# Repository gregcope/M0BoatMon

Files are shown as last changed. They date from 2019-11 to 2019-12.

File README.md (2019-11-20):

ABoatMon
========

A Moteino M0 (hence the M0) Boat Monitoring solution!

Intro
=====

A reimplementation, and extension of https://github.com/gregcope/piboatmon, as the original consumed too much power.  This is designed with the following goals;
* Be very, very low power
* Chargable from 12-24V 
* Has a rechargable LIPO battery

The present version is made from COTS parts to make life easy at the deign/proto stage.  However the code should be transferable.

Parts
=====
* [Adafruit Ultimate GPS](https://www.adafruit.com/product/746) - any 3.3v UART GPS would do, however needs an enable pin and vbat GPS almanac backup
* [Adafruit Fona](https://www.adafruit.com/product/1946) - any 3.3v UART GSM modem would do, although we do use the battery charging on the fona
* [Low power Moteino M0](https://lowpowerlab.com/shop/product/184) 
* [Mini Step Down Regulator Voltag Power Supply Module 4.5v~55v to 5v](https://www.ebay.co.uk/sch/i.html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).  Specifically the one with an enable pin and low power in off mode (<10ua).  Needs to supply 500ma+ (600ma is fine) and deal with 11-30v on the input to work on 12V or 24V systems.  Needs to supply 5V for the lipo charger.  Efficiency is not a massive issue as the regulator is off most of the time, only on to charge occassionally.
* [DS18B20 Waterproof Digital Probe Temperature Sensor with Silicone Cable (higher temp) Thermometer](https://www.ebay.co.uk/sch/i.html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)
* [12V 12mm LED Power Push Button Switch Momentary Waterproof Metal 4 Pin](https://www.ebay.co.uk/sch/i.html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)
* 1200mah LIPO Battery (any single cell LIPO with a JST would do)
* Bilge Switch (any normally closed, simple switch would do)

External Libs
=======

* [Tinygps++](https://github.com/mikalhart/TinyGPSPlus) - A class to deal with GPS
* [Lowpower](https://github.com/LowPowerLab/LowPower) - A class to help with Sleep modes
* Eeprom - Save Eeprom state
* [OneWire](https://github.com/PaulStoffregen/OneWire) - DS18B20 Temp sensor lib

Internal Classes
========
* Device - A base, or standlone class to control power to devices via a Digital pin
* Config - A class to provide a config object to store Eeprom state
* CRC8 - CRC checksum (for config saving)
* Sleep - Simple wrapper to LowPower sleep

High Level Logic
================

* Switches is on setup configures all the required parts
* Loop every 8 secs and checks;
* Bilge switch
* Every 4 mins checks the batteries
* and if above 13.7v (ie charging) enables the onboard lipo charger
* Reports bilge switch or low BatV
* Every Hour;
* Checkst the above
* Checks location
* If any of the above are out of band;
* Send a message

HowTo
=====

1. Open a command terminal, and change cd to where your Ardunio IDE stores code
```cd Documents/Arduino```
2. Clone the repo
```git clone https://github.com/gregcope/ABoatMon.git```
3. Open Ardunio IDE and open ```ABoatMon.ino```

http://arduino.stackexchange.com/questions/348/how-to-organize-my-arduino-projects-structure-for-easy-source-control

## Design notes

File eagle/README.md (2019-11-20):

# Eagle Files

0. Uses Sparkfun DRC file
1. ERC and DRC check clean
2. Top and bottom Copper Pour
3. Nets Classes use 24 mil width and 16mil clearance
4. Polygons use Isolate 12 mil
5. Layer 26 bNames - bottom silkscreen has board dimensions on it

## Design

0. I may add more parts...
1. Uses a MoteinoMega, Adafruit Ultimate GPS and an Adafruit FONA GSM
2. The P-channel Mosfet is designed to power the GPS directly, avoiding the on board regulator
3. The VBAT is on the MotinoMega 3.3V rail to keep the GPS backup circuits powered
4. The JST is for a Lipo battery
5. Their is a 1.8M/3.3M VCC voltage divider to monitor the LIPO, with a 0.1uF capacitor - see [Jeelabs post here](https://jeelabs.org/2013/05/16/measuring-the-battery-without-draining-it/)
6. Terminal Connector is for a simple Bilge switch for the Moteino to monitor
7. Terminal Connector for a Button
8. Terminal Connector for an LED
9. Terminal Connector for a DS18B20 Temp probe powered from a GPIO pin
10. Terminal Connector 12V-24V VCC input
11. A 27M/3.3M voltage divider to measure 30+V on an ADC pin
12. Headers for Fona GSM module
13. Terminal Connector for a 5v cable to connect to the Fona USB charge port
14. There is a jumper to measure the uCurrent the board uses from the LIPO, and also by-pass the switching (aka an on/off switch)
15. There is a jumper to measure the uCurrent the board uses from VCC, and also by-pass the switching (aka an on/off switch)
16. Voltage regulator uses a [holtek HT7463A](http://www.holtek.com/documents/10179/116711/HT7463A_Bv130.pdf)

... What's missing?

No thread is complete without pictures...

Eagle Schematic

Eagle Board

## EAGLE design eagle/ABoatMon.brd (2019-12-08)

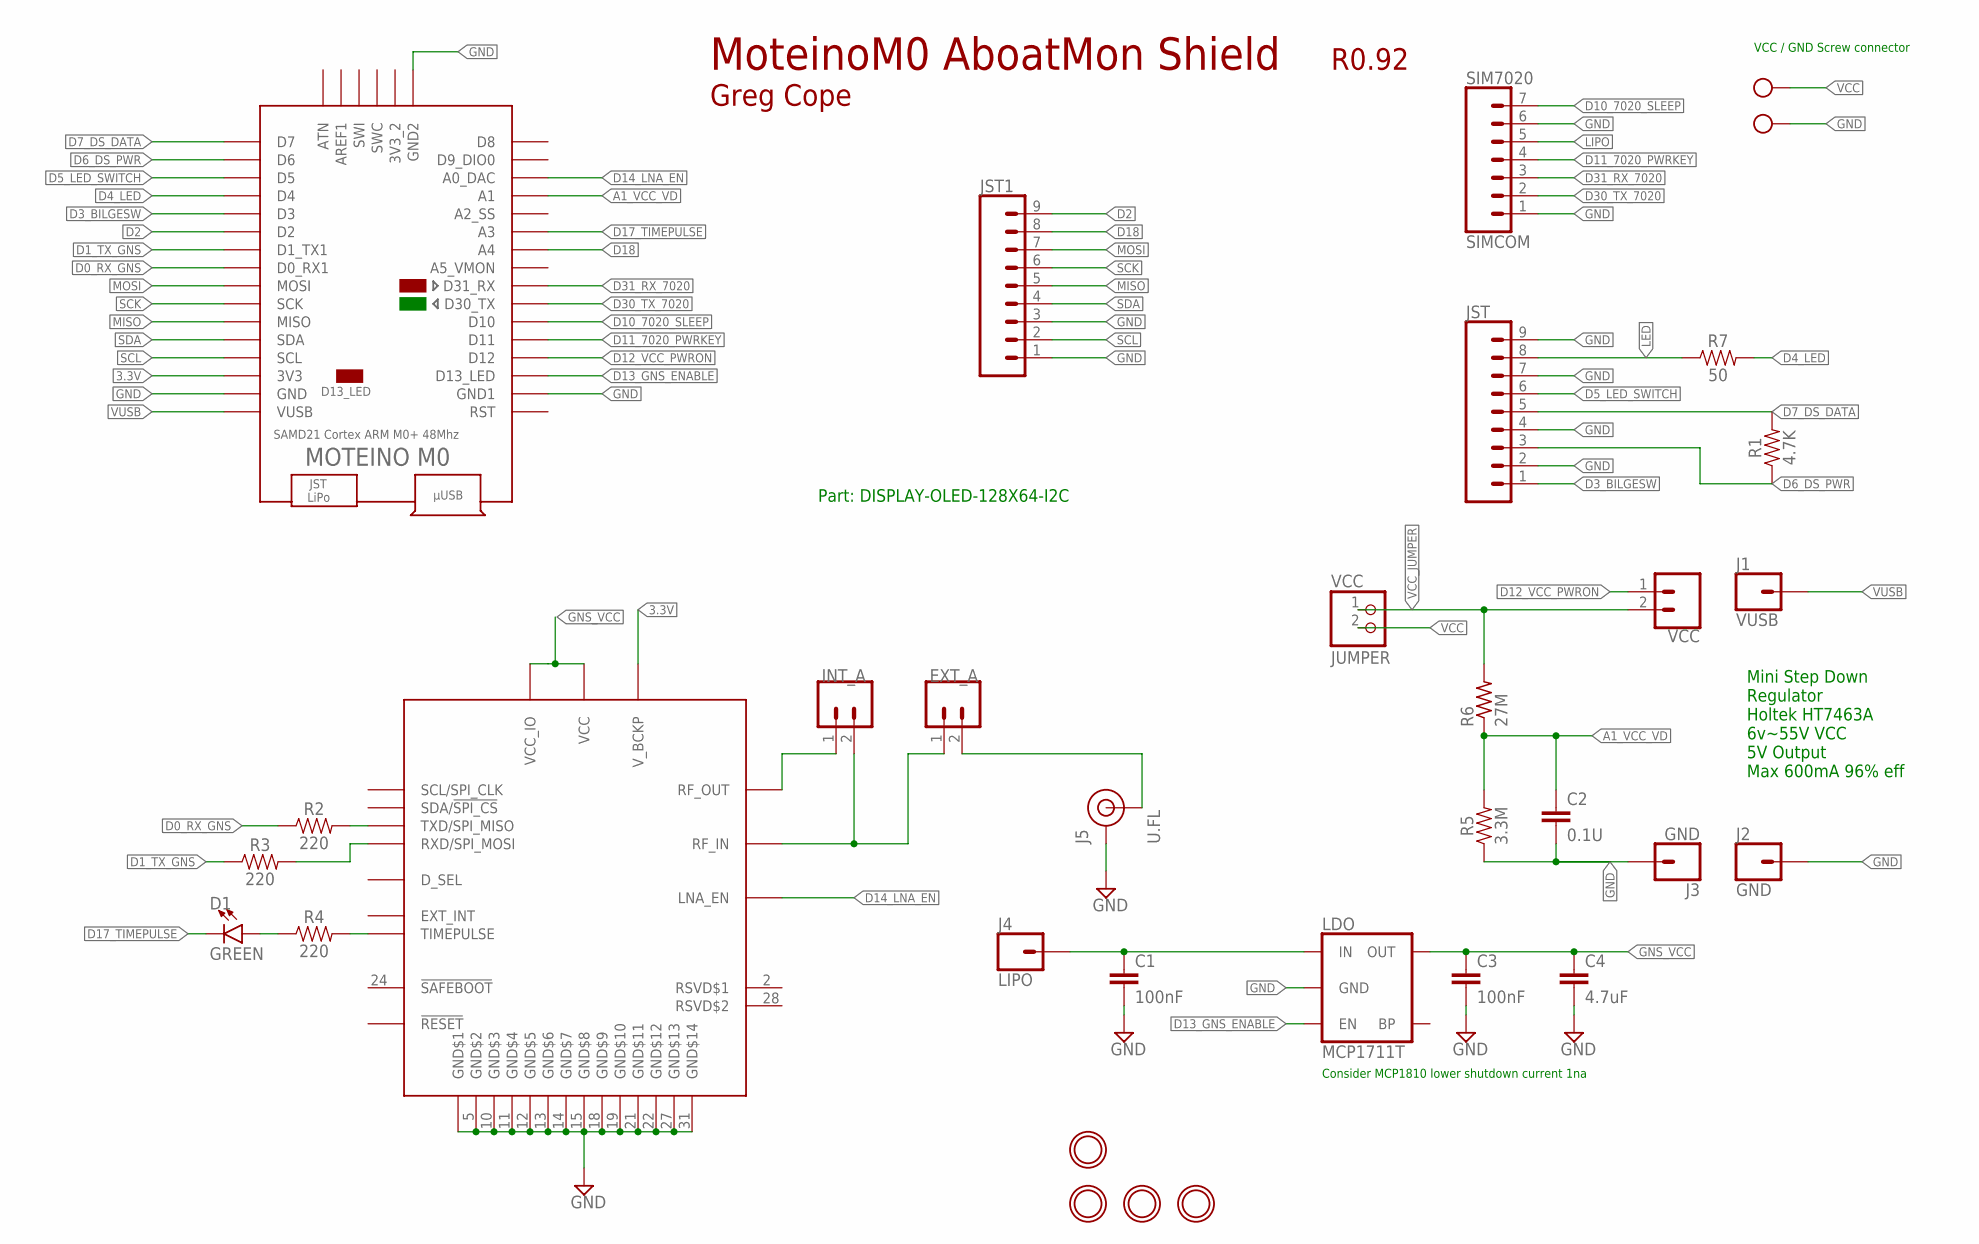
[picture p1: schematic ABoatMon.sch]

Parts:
C1, C3: 100nF; 0603
C2: 0.1U; CAP-PTH-SMALL-KIT
C4: 4.7uF; 0603
D1: GREEN; LED-0603
ENABLE: VCC; 1X02
EXT_A: CONN_02; 1X02
GND: MOUNTINGHOLE2.5; MOUNTINGHOLE_2.5_PLATED
INT_A: CONN_02; 1X02
J1: VUSB; 1X01
J2, J3: GND; 1X01
J4: LIPO; 1X01
J5: U.FL
JST, JST1: CONN_09; 1X09
LDO: MCP1711T; SOT23-5
R1: 4.7K; AXIAL-0.3
R2, R3, R4: 220; 0603
R5: 3.3M; AXIAL-0.3
R6: 27M; 0309/12
R7: 50; AXIAL-0.3
SIM7020: SIMCOM; 1X07
U$3, U$9: MOUNTINGHOLE2.0; MOUNTINGHOLE_2.0_PLATED
U$5: CAM-M8
U$6: MOTEINO_M0
U$7: MOUNTINGHOLE2.5; MOUNTINGHOLE_2.5_PLATED
VCC: JUMPER; 1X02_ROUND
X1: MKDSN1,5/2-5,08

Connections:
3.3V: U$5.8 (V_BCKP), U$6.3V3
A1_VCC_VD: C2.1, R5.P$2 (2), R6.1, U$6.A1
D0_RX_GNS: R2.1, U$6.D0_RX1
D1_TX_GNS: R3.1, U$6.D1_TX1
D2: JST1.9, U$6.D2
D3_BILGESW: JST.1, U$6.D3
D4_LED: R7.P$2 (2), U$6.D4
D5_LED_SWITCH: JST.6, U$6.D5
D6_DS_PWR: JST.3, R1.P$1 (1), U$6.D6
D7_DS_DATA: JST.5, R1.P$2 (2), U$6.D7
D10_7020_SLEEP: SIM7020.7, U$6.D10
D11_7020_PWRKEY: SIM7020.4, U$6.D11
D12_VCC_PWRON: ENABLE.1, U$6.D12
D13_GNS_ENABLE: LDO.3 (EN), U$6.D13 (D13_LED)
D14_LNA_EN: U$5.30 (LNA_EN), U$6.A0_DAC
D17_TIMEPULSE: D1.C, U$6.A3
D18: JST1.8, U$6.A4
D30_TX_7020: SIM7020.2, U$6.D30_TX
D31_RX_7020: SIM7020.3, U$6.D31_RX
GND: C1.2, C2.2, C3.2, C4.2, J2.1, J3.1, J5.1 (GND), J5.2 (GND), JST.2, JST.4, JST.7, JST.9, JST1.1, JST1.3, LDO.2 (GND), R5.P$1 (1), SIM7020.1, SIM7020.6, U$5.4 (GND$1), U$5.5 (GND$2), U$5.10 (GND$3), U$5.11 (GND$4), U$5.12 (GND$5), U$5.13 (GND$6), U$5.14 (GND$7), U$5.15 (GND$8), U$5.18 (GND$9), U$5.19 (GND$10), U$5.21 (GND$11), U$5.22 (GND$12), U$5.27 (GND$13), U$5.31 (GND$14), U$6.GND, U$6.GND_1 (GND1), U$6.GND_2 (GND2), X1.2
GNS_VCC: C3.1, C4.1, LDO.5 (OUT), U$5.1 (VCC_IO), U$5.9 (VCC)
LED: JST.8, R7.P$1 (1)
LIPO: C1.1, J4.1, LDO.1 (IN), SIM7020.5
MISO: JST1.5, U$6.MISO
MOSI: JST1.7, U$6.MOSI
unnamed: R4.2, U$5.29 (TIMEPULSE)
unnamed: R2.2, U$5.25 (TXD/SPI_MISO)
unnamed: R3.2, U$5.26 (RXD/SPI_MOSI)
unnamed: D1.A, R4.1
unnamed: EXT_A.1, INT_A.2, U$5.17 (RF_IN)
unnamed: EXT_A.2, J5.FEED (SIGNAL)
unnamed: INT_A.1, U$5.16 (RF_OUT)
SCK: JST1.6, U$6.SCK
SCL: JST1.2, U$6.SCL
SDA: JST1.4, U$6.SDA
VCC: VCC.2, X1.1
VCC_JUMPER: ENABLE.2, R6.2, VCC.1
VUSB: J1.1, U$6.VUSB

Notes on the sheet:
Mini Step Down Regulator Holtek HT7463A 6v~55V VCC 5V Output Max 600mA 96% eff
Greg Cope
R0.92
MoteinoM0 AboatMon Shield
Consider MCP1810 lower shutdown current 1na
VCC / GND Screw connector
Part: DISPLAY-OLED-128X64-I2C

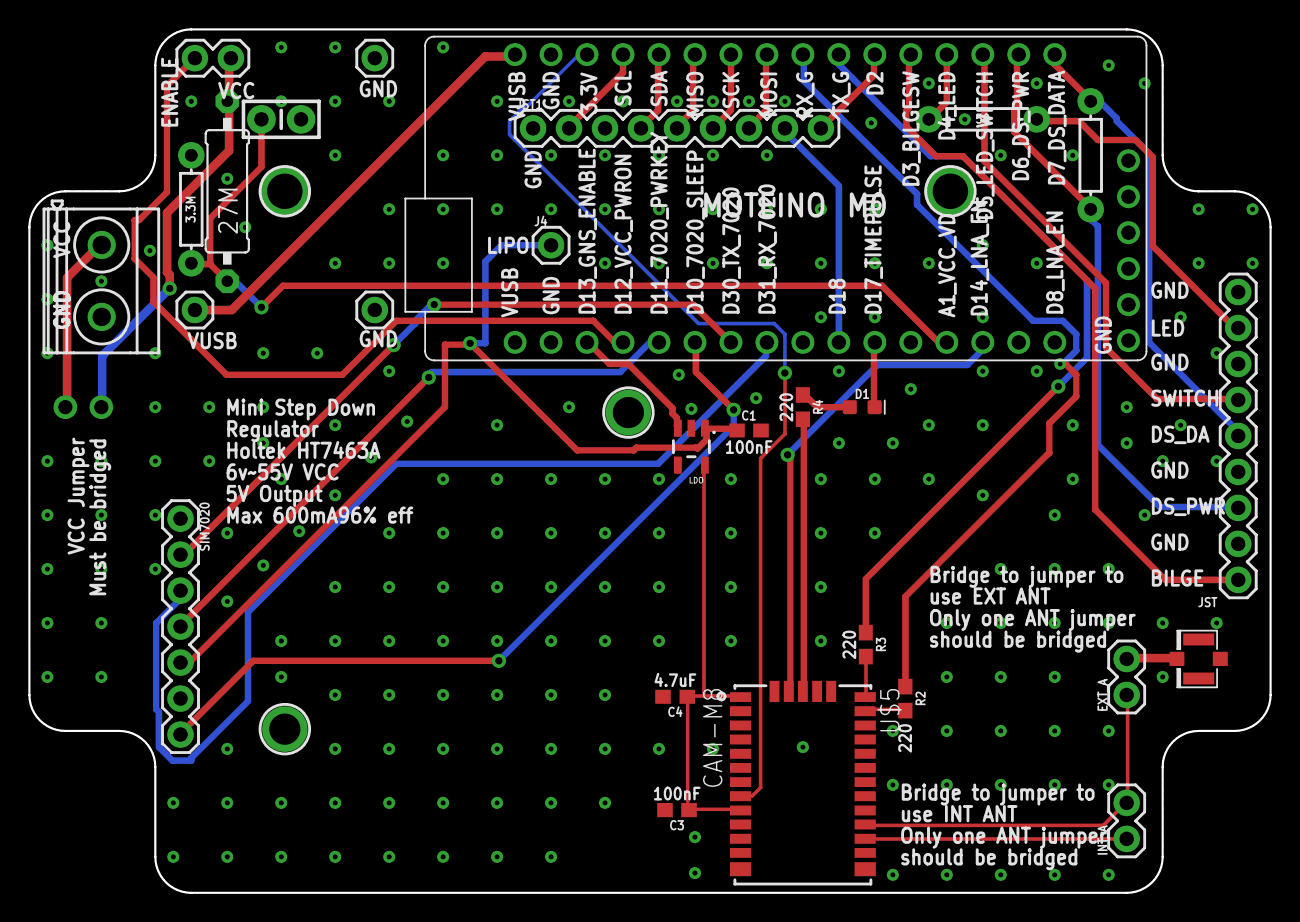
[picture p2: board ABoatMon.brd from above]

Board: 2 copper layers, 87.6 x 61.0 mm, 32 parts (0 on the bottom side), 38 nets.

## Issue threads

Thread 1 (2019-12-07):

XR JST cables rub

gregcope, 2019-12-07:
Need to move the JSR headers so that the cables route better.

Presently the board move it too far to left (from above) so that the mobile module clashes with the corner of the cover bottom left mounting arear

gregcope, 2019-12-08:
Fixed(?) in 97f1042

Closed 2019-12-08.

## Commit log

2019-01-03 added M0
    [ABoatMon.brd, ABoatMon.sch]
2019-10-27 added CAM-M8
    [ABoatMon.brd, ABoatMon.sch]
2019-10-27 started adding nets
    [ABoatMon.brd, ABoatMon.sch]
2019-10-28 moved M0 and regulator
    [ABoatMon.brd]
2019-10-28 changed nets for gns
    [ABoatMon.brd, ABoatMon.sch]
2019-10-29 first pass with vias - one airwire
    [ABoatMon.brd, ABoatMon.sch]
2019-10-31 added tab
    [ABoatMon.brd, ABoatMon.sch]
2019-11-01 added u.ft, moved GNS
    [ABoatMon.brd, ABoatMon.sch]
2019-11-04 errors cleared
    [ABoatMon.brd, ABoatMon.sch]
2019-11-04 DRC errors oshpark DRU fixed
    [ABoatMon.brd]
2019-11-04 First pass at 7020 mount holes
    [ABoatMon.brd]
2019-11-04 Silkscren fixes
    [ABoatMon.brd]
2019-11-06 added GND vias
    [ABoatMon.brd]
2019-11-09 ABoatMon_2019-11-07.zip R2 sent to fab
    [ABoatMon.brd, ABoatMon.sch]
2019-11-20 Started R0.9 1. Mounting hole wrong place 2. Regulator board needs to move down due to overlapping edge of casterlated holes 3. Mobile module needs to move right 1mm due to sharp lower left edge hitt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
    [ABoatMon.brd, ABoatMon.sch]
2019-11-20 Mounting hole and ufl moved
    [ABoatMon.brd, ABoatMon.sch]
2019-11-20 pushed out tab sizes on either end
    [ABoatMon.brd, ABoatMon.sch]
2019-11-20 fixed a radius to 100
    [ABoatMon.brd]
2019-11-20 rebased, 100 radius fixed, added GND vias
    [ABoatMon.brd]
2019-11-20 removed wires
    [ABoatMon.brd, ABoatMon.sch]
2019-11-20 Moved LIPO label, all fixes done
    [ABoatMon.brd]
2019-11-23 D7000 wrong way round, moved 10pin jst
    [ABoatMon.brd]
2019-11-23 Moved power jumper, added jumper txt
    [ABoatMon.brd]
2019-11-23 Clearance DRC errors fixed
    [ABoatMon.brd]
2019-11-24 DRC, ERC checked. Moved routes away from GNS chip
    [ABoatMon.brd]
2019-11-24 removed a wire stub
    [ABoatMon.brd]
2019-11-24 removed too many wire stubs. DRC and ERC pass now
    [ABoatMon.brd]
2019-11-25 added a via, move a trace
    [ABoatMon.brd, ABoatMon.sch]
2019-12-08 Moved JSTs
    [ABoatMon.brd, ABoatMon.sch]
2019-12-08 Moved SIM7000 up a bit
    [ABoatMon.brd, ABoatMon.sch]

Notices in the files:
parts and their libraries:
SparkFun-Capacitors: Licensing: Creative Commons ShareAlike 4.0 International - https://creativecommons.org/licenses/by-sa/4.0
